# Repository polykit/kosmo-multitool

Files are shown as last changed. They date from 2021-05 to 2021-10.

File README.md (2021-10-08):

# Kosmo Multitool

This repository contains schematics, PCB and source code for a synthesizer module in Kosmo format. This module consists of an Arduino Nano Every, CV and gate input and output options, MIDI, rotary encoder and an OLED display. It is meant as a development platform for DIY synthesizer enthusiasts.

Here is a full list of features:
- 4x CV input (0-10V)
- 4x CV output (0-10V)
- 4x gate/trigger in
- 4x gate/trigger out
- 1.3" OLED display
- DIN serial MIDI in/through/out
- Rotary encoder with switch
- 3 switches
- 2 LEDs

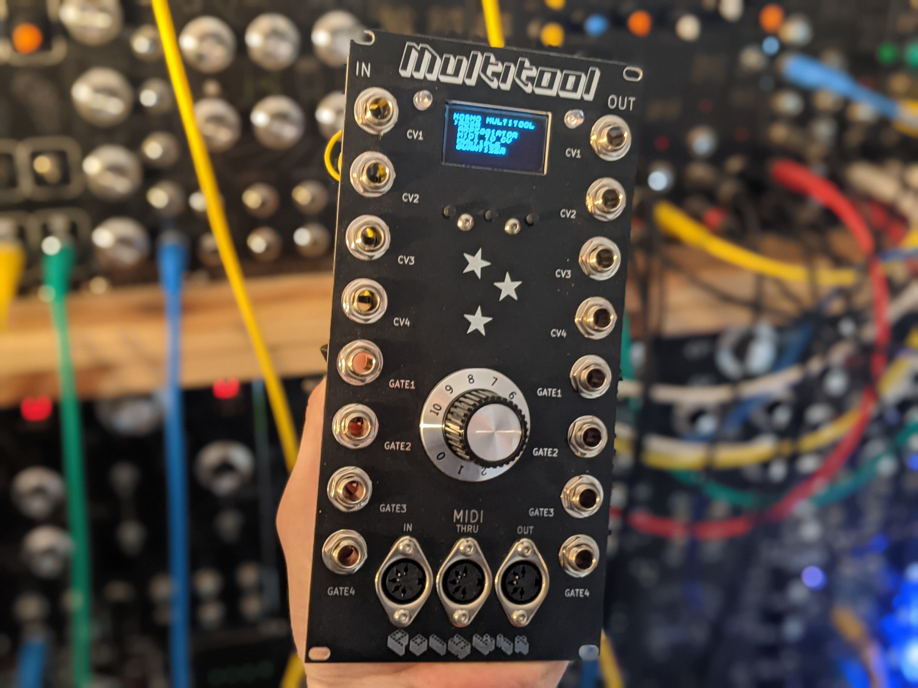
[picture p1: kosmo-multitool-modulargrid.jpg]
Kosmo Multitool Assembled


## Modules

- ADSR
- Arpeggiator
- MIDI to CV
- Multiple
- Quantizer

## Building

Gerbers for the main PCB can be found [here](plots) and for the front panel [here](panel/plots).

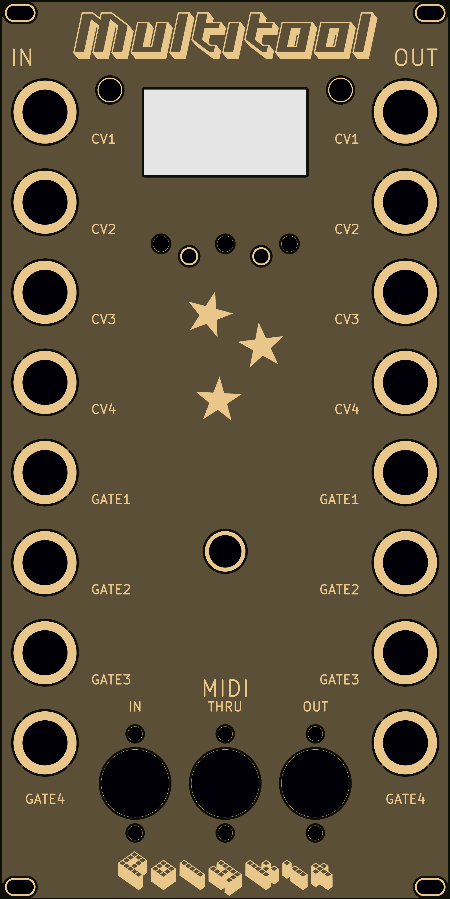
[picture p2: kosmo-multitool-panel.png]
Kosmo Multitool Panel
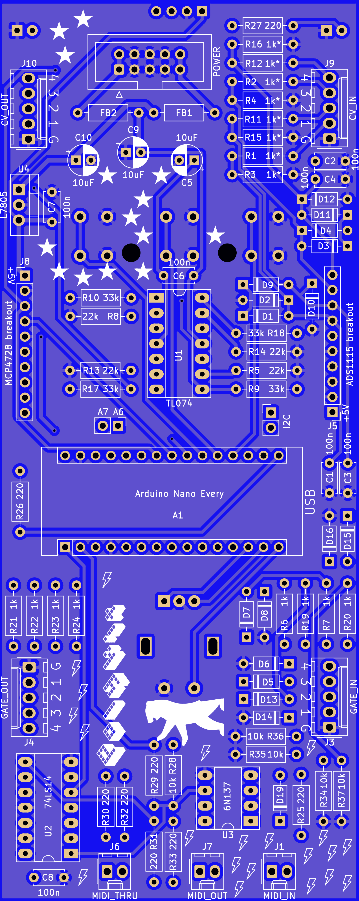
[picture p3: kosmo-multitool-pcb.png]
Kosmo Multitool PCB
 

### BOM

|Reference |Quantity|Value |Comment |
|---|---|---|---|
|A1 |1 |Arduino Nano Every | |
|C1 C2 C3 C4 C6 C7 C8 |7 |100n | |
|C5 C9 C10 |3 |10uF | |
|D17 D18 |2 |LED 5mm | |
|D1 D2 D3 D4 D5 D6 D7 D8 D9 D10 D11 D12 D13 D14 D15 D16 D19 |17 |1N4148 | |
|FB1 FB2 |2 |Ferrite Bead | |
|J1 |1 |MIDI_IN |Molex KK 2.54mm 2 pin |
|J10 |1 |CV_OUT |Molex KK 2.54mm 5 pin |
|J2 |1 |Display I2C |OLED display 1.3" 128x64 I2C SH1106 |
|J3 |1 |GATE_IN |Molex KK 2.54mm 5 pin |
|J4 |1 |GATE_OUT |Molex KK 2.54mm 5 pin |
|J5 |1 |ADS1115 breakout |ADC, pin order: VCC GND SCL SDA ADDR ALERT A B C D|
|J6 |1 |MIDI_THRU |Molex KK 2.54mm 2 pin |
|J7 |1 |MIDI_OUT |Molex KK 2.54mm 2 pin |
|J8 |1 |MCP4728 breakout |DAC, pin order: VCC GND SCL SDA LDAC READY A B C D|
|J9 |1 |CV_IN |Molex KK 2.54mm 5 pin |
|POWER1 |1 |POWER |IDC 10 pin |
|R1 R2 R3 R4 R11 R12 R15 R16 |8 |1k* | |
|R5 R8 R13 R14 |4 |22k | |
|R9 R10 R17 R18 |4 |33k | |
|R25 R26 R27 R29 R30 R31 R32 R33 |8 |220 | |
|R28 R34 R35 R36 R37 |5 |10k | |
|R6 R7 R19 R20 R21 R22 R23 R24 |8 |1k | |
|SW1 SW2 SW3 |3 |SW_Push |Tactile Push Button 6x6x15mm |
|SW4 |1 |Rotary_Encoder_Switch|Rotary encoder with switch, 20mm |
|U1 |1 |TL074 | |
|U2 |1 |74LS14 | |
|U3 |1 |6N137 | |
|U4 |1 |L7805 | |
| | |Pin sockets, 2.54mm  |Needed for the Arduino, OLED display, ADC and DAC |
| |16 |Jack sockets 6.35mm  | |
| |3 |DIN MIDI sockets | |

\* match in pairs to get more accurate ADC readings

## Installation and calibration

Clone the repository and open up the `src/main` folder in the Arduino IDE or whatever you use for compiling. You need to install the libraries mentioned below into you Arduino library folder. The ADC and the DAC need calibration to get proper results.

### ADC calibration
Set `CALIBRATE_CV_IN` variable in main file to `1`. Apply a fixed, known voltage to CV1 input, eg. 5.000V. On USB serial console (9600 baud) you get the actual reading from the ADC. Calculate the correction factor `FIXED VOLTAGE / ACTUAL VOLTAGE`, eg. `5.000 / 4.9884 = 1.0023`. Enter the value in the CV_IN_CORRECTION array in the top lines of `main.ino`. Repeat this procedure for all CV inputs. In the end it should look something like this:
```
float CV_IN_CORRECTION[4] = {0.9995f, 0.9956f, 1.0013f, 1.0009f};
```
Notice the trailing `f` to tell the compiler that these are float values. Don't forget to set `CALIBRATE_CV_IN` back to `0`.

### DAC calibration
Make sure to calibrate the ADC first. Set `CALIBRATE_CV_OUT` variable in main file to `1`. Plug in patch cables from all four CV inputs to the CV outputs. Calibration is done automatically and stored in a look-up table. Set `CALIBRATE_CV_OUT` back to `0`. This step is only needed once, from now on calibration values are loaded from EEPROM on start up.

## Development

Source code is in `src/main`. If you want to develop your own module just copy the files `example_module.h` and `example_module.ino` and rename all functions and variables that are globally available. Include your header file in the `main.ino` file and add your entry to the main menu. Take a look at the already existing modules on how it works in general. If you created a nice module please file a pull request and I would be happy to merge it.

## Libraries

https://github.com/adafruit/Adafruit_MCP4728

https://github.com/adafruit/Adafruit_ADS1X15

https://github.com/olikraus/u8g2

https://github.com/FortySevenEffects/arduino_midi_library

https://github.com/neu-rah/ArduinoMenu

https://github.com/thomasfredericks/Bounce2

https://github.com/mathertel/RotaryEncoder

https://github.com/ivanseidel/LinkedList

## References

https://www.lookmumnocomputer.com/modular

https://www.ti.com/lit/ds/symlink/ads1115.pdf

http://ww1.microchip.com/downloads/en/devicedoc/22187e.pdf

https://github.com/DylanMeeus/GoAudio

## License

This work is licensed under a [Creative Commons Attribution-NonCommercial 4.0 International License](http://creativecommons.org/licenses/by-nc/4.0/).

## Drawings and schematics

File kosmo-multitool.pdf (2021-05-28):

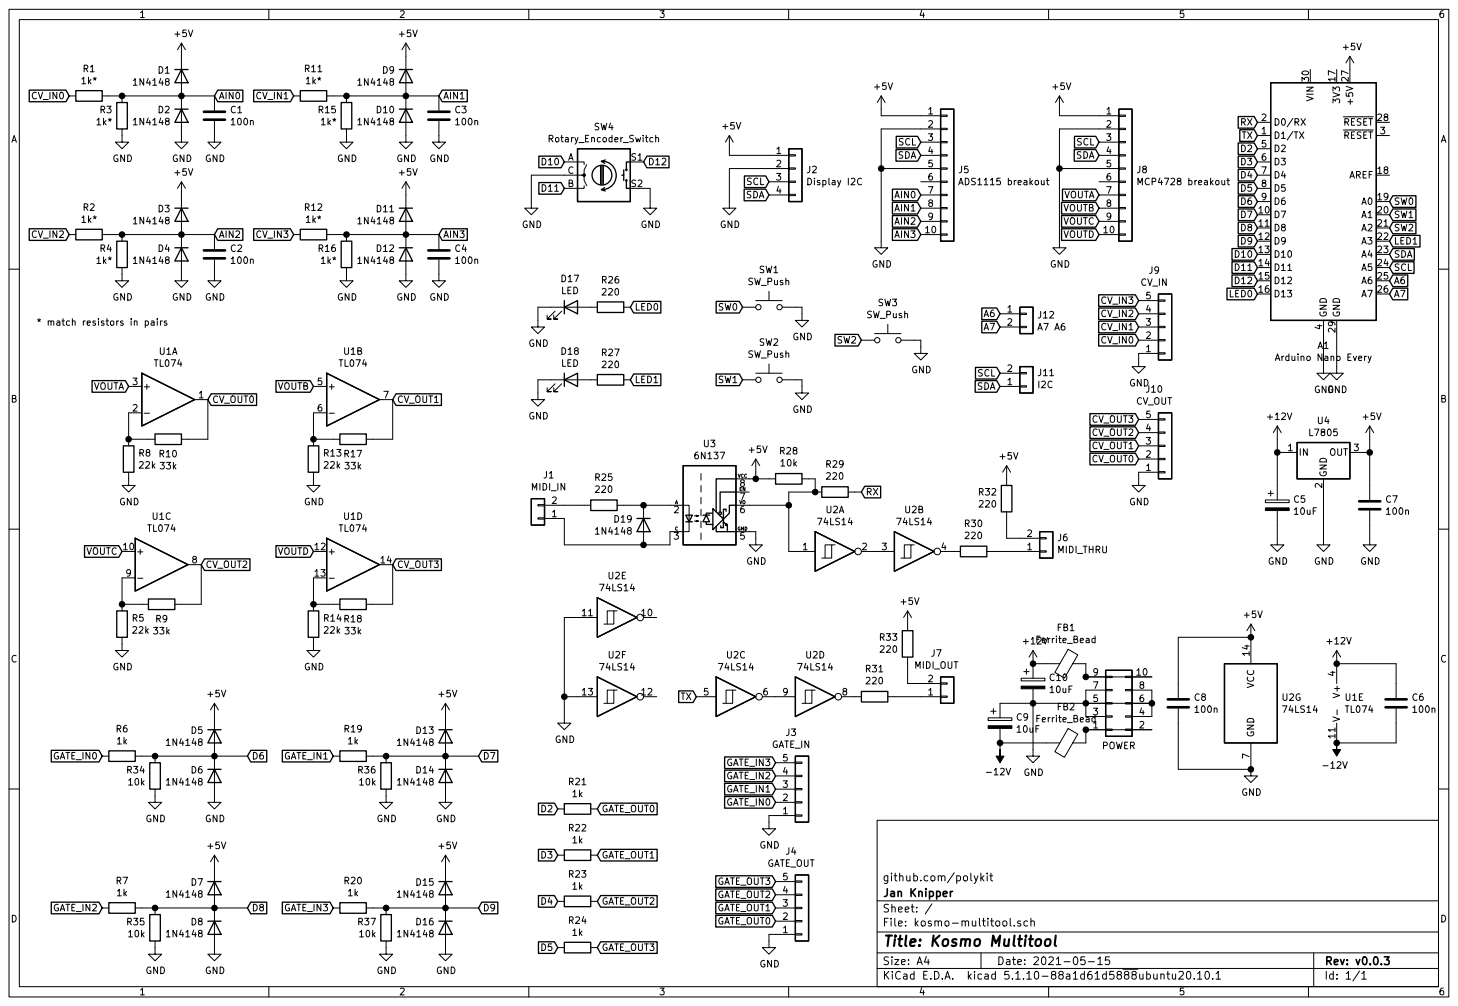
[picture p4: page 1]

* match resistors in pairs

Id: 1/1 Title: Kosmo Multitool File: kosmo-multitool.sch Sheet: / Jan Knipper

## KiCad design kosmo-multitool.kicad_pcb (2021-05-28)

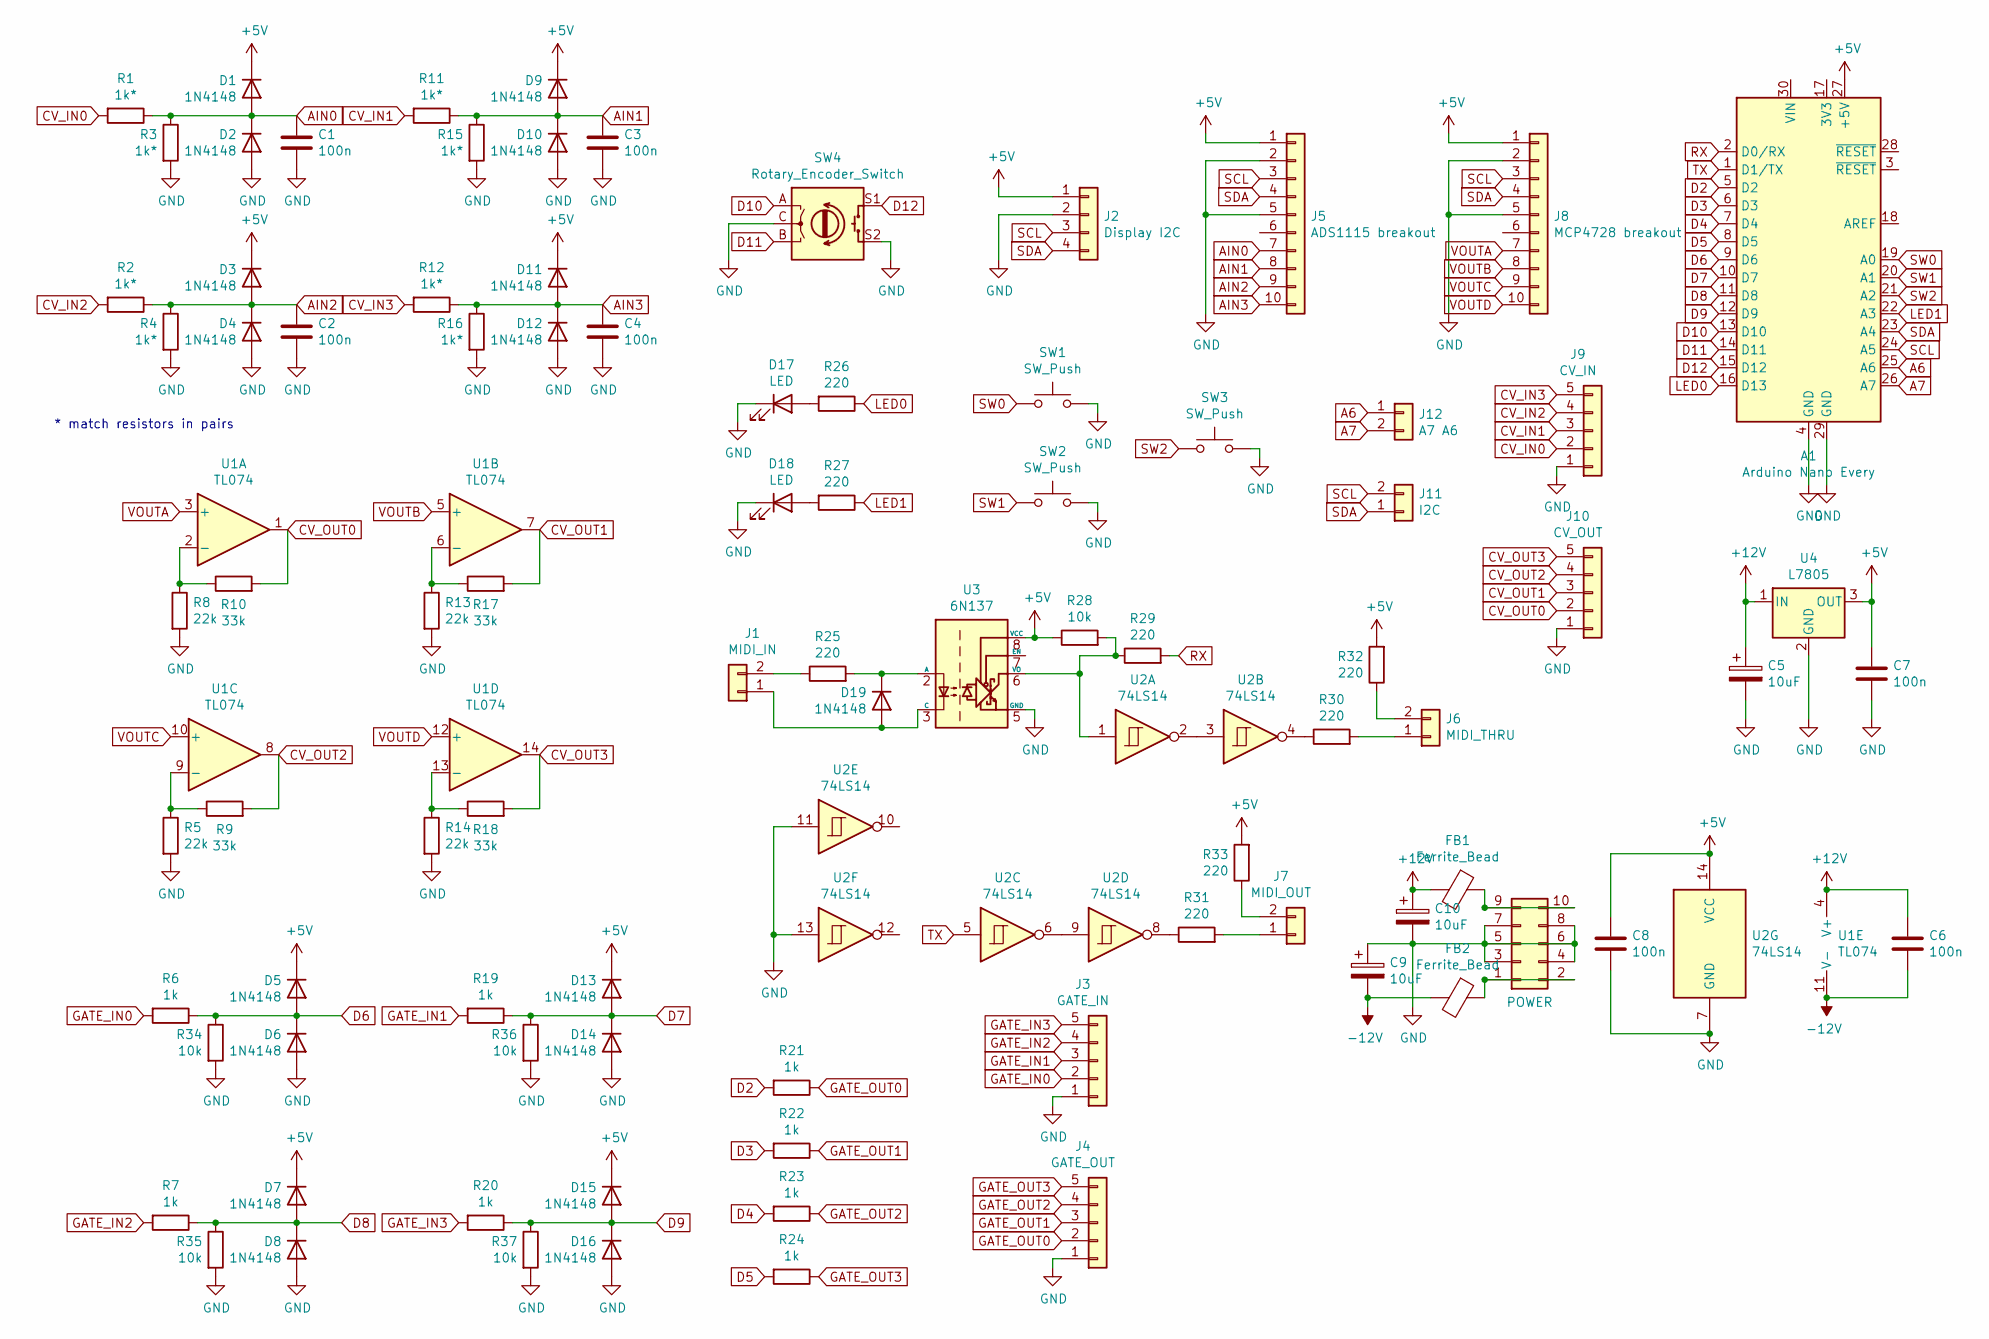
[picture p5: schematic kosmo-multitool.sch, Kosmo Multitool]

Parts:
A1: Arduino Nano Every; Arduino_Nano
C1, C2, C3, C4, C6, C7, C8: 100n; C_Disc_D5.0mm_W2.5mm_P5.00mm
C5, C9, C10: 10uF; CP_Radial_D5.0mm_P2.50mm
D1, D2, D3, D4, D5, D6, D7, D8, D9, D10, D11, D12, D13, D14, D15, D16, D19: 1N4148; D_DO-35_SOD27_P7.62mm_Horizontal
D17, D18: LED; LED_D5.0mm
FB1, FB2: Ferrite_Bead; R_Axial_DIN0207_L6.3mm_D2.5mm_P10.16mm_Horizontal
J1: MIDI_IN; Molex_KK-254_AE-6410-02A_1x02_P2.54mm_Vertical
J2: Display I2C; PinHeader_1x04_P2.54mm_Vertical
J3: GATE_IN; Molex_KK-254_AE-6410-05A_1x05_P2.54mm_Vertical
J4: GATE_OUT; Molex_KK-254_AE-6410-05A_1x05_P2.54mm_Vertical
J5: ADS1115 breakout; PinHeader_1x10_P2.54mm_Vertical
J6: MIDI_THRU; Molex_KK-254_AE-6410-02A_1x02_P2.54mm_Vertical
J7: MIDI_OUT; Molex_KK-254_AE-6410-02A_1x02_P2.54mm_Vertical
J8: MCP4728 breakout; PinHeader_1x10_P2.54mm_Vertical
J9: CV_IN; Molex_KK-254_AE-6410-05A_1x05_P2.54mm_Vertical
J10: CV_OUT; Molex_KK-254_AE-6410-05A_1x05_P2.54mm_Vertical
J11: I2C; PinHeader_1x02_P2.54mm_Vertical
J12: A7 A6; PinHeader_1x02_P2.54mm_Vertical
POWER1: POWER; IDC-Header_2x05_P2.54mm_Vertical
R1, R2, R3, R4, R11, R12, R15, R16: 1k*; R_Axial_DIN0207_L6.3mm_D2.5mm_P10.16mm_Horizontal
R5, R8, R13, R14: 22k; R_Axial_DIN0207_L6.3mm_D2.5mm_P10.16mm_Horizontal
R6, R7, R19, R20, R21, R22, R23, R24: 1k; R_Axial_DIN0207_L6.3mm_D2.5mm_P10.16mm_Horizontal
R9, R10, R17, R18: 33k; R_Axial_DIN0207_L6.3mm_D2.5mm_P10.16mm_Horizontal
R25, R26, R27, R29, R30, R31, R32, R33: 220; R_Axial_DIN0207_L6.3mm_D2.5mm_P10.16mm_Horizontal
R28, R34, R35, R36, R37: 10k; R_Axial_DIN0207_L6.3mm_D2.5mm_P10.16mm_Horizontal
SW1, SW2, SW3: SW_Push; SW_PUSH_6mm_H13mm
SW4: Rotary_Encoder_Switch; RotaryEncoder_Alps_EC11E-Switch_Vertical_H20mm
U1: TL074; DIP-14_W7.62mm_Socket_LongPads
U2: 74LS14; DIP-14_W7.62mm_Socket_LongPads
U3: 6N137; DIP-8_W7.62mm_Socket_LongPads
U4: L7805; TO-220-3_Vertical

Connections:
+5V: A1.27 (+5V), C7.1, C8.1, D1.1 (K), D3.1 (K), D5.1 (K), D7.1 (K), D9.1 (K), D11.1 (K), D13.1 (K), D15.1 (K), J2.1, J5.1, J8.1, R28.1, R32.2, R33.2, U2.14 (VCC), U3.8 (VCC), U4.3 (OUT)
+12V: C5.1, C6.1, C10.1, FB1.2, U1.4 (V+), U4.1 (IN)
-12V: C6.2, C9.2, FB2.2, U1.11 (V-)
A6: A1.25 (A6), J12.1
A7: A1.26 (A7), J12.2
AIN0: C1.1, D1.2 (A), D2.1 (K), J5.7, R1.1, R3.1
AIN1: C3.1, D9.2 (A), D10.1 (K), J5.8, R11.1, R15.1
AIN2: C2.1, D3.2 (A), D4.1 (K), J5.9, R2.1, R4.1
AIN3: C4.1, D11.2 (A), D12.1 (K), J5.10, R12.1, R16.1
CV_IN0: J9.2, R1.2
CV_IN1: J9.3, R11.2
CV_IN2: J9.4, R2.2
CV_IN3: J9.5, R12.2
CV_OUT0: J10.2, R10.2, U1.1
CV_OUT1: J10.3, R17.2, U1.7
CV_OUT2: J10.4, R9.2, U1.8
CV_OUT3: J10.5, R18.2, U1.14
D2: A1.5 (D2), R21.2
D3: A1.6 (D3), R22.2
D4: A1.7 (D4), R23.2
D5: A1.8 (D5), R24.2
D6: A1.9 (D6), D5.2 (A), D6.1 (K), R6.1, R34.1
D7: A1.10 (D7), D13.2 (A), D14.1 (K), R19.1, R36.1
D8: A1.11 (D8), D7.2 (A), D8.1 (K), R7.1, R35.1
D9: A1.12 (D9), D15.2 (A), D16.1 (K), R20.1, R37.1
D10: A1.13 (D10), SW4.A
D11: A1.14 (D11), SW4.B
D12: A1.15 (D12), SW4.S1
GATE_IN0: J3.2, R6.2
GATE_IN1: J3.3, R19.2
GATE_IN2: J3.4, R7.2
GATE_IN3: J3.5, R20.2
GATE_OUT0: J4.2, R21.1
GATE_OUT1: J4.3, R22.1
GATE_OUT2: J4.4, R23.1
GATE_OUT3: J4.5, R24.1
GND: A1.4 (GND), A1.29 (GND), C1.2, C2.2, C3.2, C4.2, C5.2, C7.2, C8.2, C9.1, C10.2, D2.2 (A), D4.2 (A), D6.2 (A), D8.2 (A), D10.2 (A), D12.2 (A), D14.2 (A), D16.2 (A), D17.1 (K), D18.1 (K), J2.2, J3.1, J4.1, J5.2, J5.5, J8.2, J8.5, J9.1, J10.1, POWER1.3, POWER1.4, POWER1.5, POWER1.6, POWER1.7, POWER1.8, R3.2, R4.2, R5.2, R8.2, R13.2, R14.2, R15.2, R16.2, R34.2, R35.2, R36.2, R37.2, SW1.2, SW2.2, SW3.2, SW4.C, SW4.S2, U2.7 (GND), U2.11, U2.13, U3.5 (GND), U4.2 (GND)
LED0: A1.16 (D13), R26.1
LED1: A1.22 (A3), R27.1
unnamed: D17.2 (A), R26.2
unnamed: D18.2 (A), R27.2
unnamed: D19.1 (K), R25.2, U3.2 (A)
unnamed: D19.2 (A), J1.1, U3.3 (C)
unnamed: FB1.1, POWER1.9, POWER1.10
unnamed: FB2.1, POWER1.1, POWER1.2
unnamed: J1.2, R25.1
unnamed: J6.1, R30.2
unnamed: J6.2, R32.1
unnamed: J7.1, R31.2
unnamed: J7.2, R33.1
unnamed: R5.1, R9.1, U1.9 (-)
unnamed: R8.1, R10.1, U1.2 (-)
unnamed: R13.1, R17.1, U1.6 (-)
unnamed: R14.1, R18.1, U1.13 (-)
unnamed: R28.2, R29.1, U2.1, U3.6 (VO)
unnamed: R30.1, U2.4
unnamed: R31.1, U2.8
unnamed: U2.2, U2.3
unnamed: U2.6, U2.9
RX: A1.2 (D0/RX), R29.2
SCL: A1.24 (A5), J2.3, J5.3, J8.3, J11.2
SDA: A1.23 (A4), J2.4, J5.4, J8.4, J11.1
SW0: A1.19 (A0), SW1.1
SW1: A1.20 (A1), SW2.1
SW2: A1.21 (A2), SW3.1
TX: A1.1 (D1/TX), U2.5
VOUTA: J8.7, U1.3 (+)
VOUTB: J8.8, U1.5 (+)
VOUTC: J8.9, U1.10 (+)
VOUTD: J8.10, U1.12 (+)

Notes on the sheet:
* match resistors in pairs

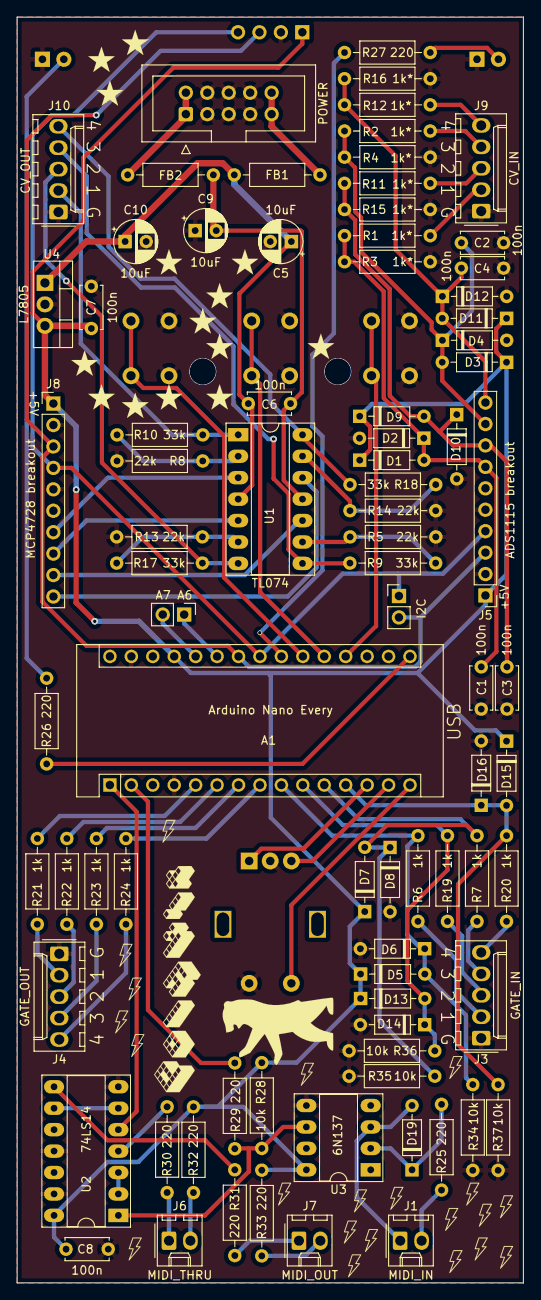
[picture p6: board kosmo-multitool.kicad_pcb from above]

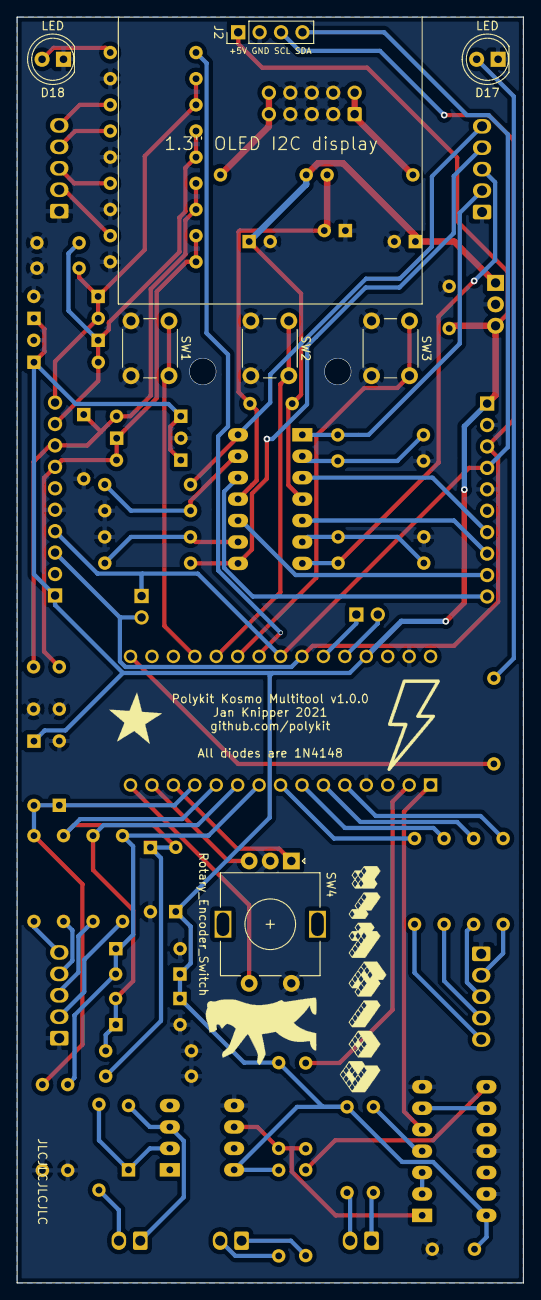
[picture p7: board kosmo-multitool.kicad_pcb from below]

Board: 2 copper layers, 60.0 x 150.0 mm, 90 parts (7 on the bottom side), 70 nets.

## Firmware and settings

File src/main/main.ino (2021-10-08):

#include <Arduino.h>
#include <EEPROM.h>
#include <Wire.h>

#include <Adafruit_ADS1X15.h>
#include <Adafruit_MCP4728.h>
#include <MIDI.h>
#include <menu.h>
#include <menuIO/U8x8Out.h>
#include <U8x8lib.h>
#include <RotaryEncoder.h>
#include <Bounce2.h>
#include <LinkedList.h>

//#include "example_module.h"
#include "adsr.h"
#include "arp.h"
#include "midi2cv.h"
#include "multiple.h"
#include "quantizer.h"

#define DEBUG 1
#define CALIBRATE_CV_IN 0
#define CALIBRATE_CV_OUT 0

float CV_IN_CORRECTION[4] = {1.0000f, 1.0000f, 1.0000f, 1.0000f};
unsigned int CV_OUT_LUT[4][21];
int LED_PINS[2] = {13, A3};
int GATE_IN_PINS[4] = {6, 7, 8, 9};
int GATE_OUT_PINS[4] = {2, 3, 4, 5};
unsigned long GATE_OUT_DURATION[4];
int SWITCH_PINS[4] = {A0, A1, A2, 12};
Bounce2::Button SWITCHES[4];
int MIDI_CHANNEL = 1;
int OCTAVE_OFFSET = 3;
LinkedList<byte> MIDI_NOTES_ACTIVE;
void (*activeModule)(void);

Adafruit_ADS1115 ads;
Adafruit_MCP4728 mcp;
U8X8_SH1106_128X64_NONAME_HW_I2C u8x8(U8X8_PIN_NONE);
MIDI_CREATE_INSTANCE(HardwareSerial, Serial1, MIDI);
RotaryEncoder encoder(10, 11, RotaryEncoder::LatchMode::TWO03);

// menu
MENU(mainMenu,"KOSMO MULTITOOL",doNothing,noEvent,wrapStyle
  //,SUBMENU(subMenuExample)
  ,SUBMENU(subMenuADSR)
  ,SUBMENU(subMenuArp)
  ,SUBMENU(subMenuMidi2CV)
  ,SUBMENU(subMenuMultiple)
  ,SUBMENU(subMenuQuantizer)
);
#define MAX_DEPTH 3
noInput in;
MENU_OUTPUTS(out,MAX_DEPTH,U8X8_OUT(u8x8,{0,0,17,8}),NONE);
NAVROOT(nav,mainMenu,MAX_DEPTH,in,out);

void setup(void) {
  if (DEBUG) {
    Serial.begin(9600);
    Serial.println("Polykit Multitool. Initializing...");
  }
  
  // initialize adc
  ads.setGain(GAIN_TWOTHIRDS);
  ads.begin();

  // initialize dac
  mcp.begin();

  // init midi
  MIDI.setHandleNoteOn(handleNoteOn);
  MIDI.setHandleNoteOff(handleNoteOff);
  MIDI.begin(MIDI_CHANNEL);

  // init display
  u8x8.begin();
  u8x8.setFont(u8x8_font_chroma48medium8_u);
  
  for (int i=0; i<2; i++) {
    pinMode(LED_PINS[i], OUTPUT);
  }

  for (int i=0; i<4; i++) {
    pinMode(GATE_IN_PINS[i], INPUT);
    pinMode(GATE_OUT_PINS[i], OUTPUT);
    GATE_OUT_DURATION[i] = 0;
  }

  for (int i=0; i<4; i++) {
    SWITCHES[i] = Bounce2::Button();
    SWITCHES[i].attach(SWITCH_PINS[i], INPUT_PULLUP);
    SWITCHES[i].interval(10); 
    SWITCHES[i].setPressedState(LOW); 
  } 

  if (CALIBRATE_CV_IN) {
    u8x8.drawString(0,0,"CALIBRATING...");
    calibrateCVIn();
    u8x8.drawString(0,1,"DONE");
    while (1);
  } 

  if (CALIBRATE_CV_OUT) {
    u8x8.drawString(0,0,"CALIBRATING...");
    calibrateCVOut();
    u8x8.drawString(0,1,"DONE");
    while (1);
  } else {
    u8x8.drawString(0,0,"LOADING...");
    int addr = 0;
    for (int c=0; c<4; c++) {
      CV_OUT_LUT[c][0] = 0;
      for (int i=1; i<=20; i++) {
        EEPROM.get(addr, CV_OUT_LUT[c][i]);
        addr += sizeof(unsigned int);
      }
    }
  }

  for (int i=0; i<4; i++) {
    setLEDOn(0);
    setLEDOff(1);
    delay(100);
    setLEDOn(1);
    setLEDOff(0);
    delay(100);
  }
  setLEDOff(1);
}

void loop(void) {
  MIDI.read();
  encoder.tick();
  nav.poll();
  handleMenu();
  handleGateOutDurations();
  handleSwitches();
  if (activeModule) {
    activeModule();
  }
}

void handleNoteOn(byte channel, byte note, byte velocity) {
  if (channel != MIDI_CHANNEL) return;
  MIDI_NOTES_ACTIVE.add(note);
}

void handleNoteOff(byte channel, byte note, byte velocity) {
  if (channel != MIDI_CHANNEL) return;
  for (int i=0; i<MIDI_NOTES_ACTIVE.size(); i++) {
    if (MIDI_NOTES_ACTIVE.get(i) == note) {
      MIDI_NOTES_ACTIVE.remove(i);
      return;
    }
  }
}

float getCVFromNote(byte note) {
  return (note-12*OCTAVE_OFFSET)/12.0f;
}

void handleMenu() {
  int dir = getEncoderDir();
  if (dir == (int)RotaryEncoder::Direction::COUNTERCLOCKWISE) {
    nav.doNav(navCmd(downCmd));
  } else if(dir == (int)RotaryEncoder::Direction::CLOCKWISE) {
    nav.doNav(navCmd(upCmd));    
  }
  if (isSwitchOn(3)) {
    nav.doNav(navCmd(enterCmd));
  }
}

int getEncoderDir() {
  return (int)encoder.getDirection();
}

int getEncoderPos() {
  return encoder.getPosition();
}

float getCVIn(int n, bool correct) {
  if (n>3) return -1;
  
  int16_t adc = ads.readADC_SingleEnded(n);
  float cv = ads.computeVolts(adc)*2;
  
  if (correct) {
    cv = cv*CV_IN_CORRECTION[n];
  }
  
  return cv;
}

void setCVOut(int n, float v, bool correct) {
  if (n>3) return;
  if (v>10) return;
  
  MCP4728_channel_t ch;
  if (n==0) ch = MCP4728_CHANNEL_A;
  if (n==1) ch = MCP4728_CHANNEL_B;
  if (n==2) ch = MCP4728_CHANNEL_C;
  if (n==3) ch = MCP4728_CHANNEL_D;
  int nv = map(v*1000, 0, 10000, 0, 4095);

  if (correct) {
    int pos = round(2*v);
    nv = nv*(CV_OUT_LUT[n][pos]/1000.0f);
  }

  mcp.setChannelValue(ch, nv, MCP4728_VREF_INTERNAL, MCP4728_GAIN_2X);
}

void calibrateCVIn() {
  if (DEBUG) Serial.println("ADC calibration started.");
  int numSamples = 20;
  for (int n=0; n<4; n++) {
    if (DEBUG) {
      Serial.print("CV");
      Serial.print(n);
      Serial.print("CV");
    }
    float cv = 0;
    for (int i=0; i<numSamples; i++) {
      cv += getCVIn(n, false);
    }
    if (DEBUG) Serial.println((cv/numSamples), 4);
  }
  if (DEBUG) Serial.println("ADC calibration ended.");
}

void calibrateCVOut() {
  if (DEBUG) Serial.println("DAC calibration started.");
  int numSamples = 20;
  float cv;
  int addr = 0;
  for (int c=0; c<4; c++) {
    if (DEBUG) {
      Serial.print("Channel: ");
      Serial.println(c);
    }
    CV_OUT_LUT[c][0] = 0;
    for (int i=1; i<=20; i++) {
      setCVOut(c, i*0.5f, false);
      delay(100);
      cv = 0;
      for (int j=0; j<numSamples; j++) {
        cv += getCVIn(c, true);
      }
      cv = cv/numSamples;
      CV_OUT_LUT[c][i] = round(1000*i*0.5f/cv);
      if (DEBUG) {
        Serial.print("Wanted: ");
        Serial.println(i*0.5f, 4);
        Serial.print("Real: ");
        Serial.println(cv, 4);
        Serial.print("LUT: ");
        Serial.println(CV_OUT_LUT[c][i]/1000.0f, 4);
      }
      EEPROM.put(addr, CV_OUT_LUT[c][i]);
      addr += sizeof(unsigned int);
    }
  }
  if (DEBUG) Serial.println("DAC calibration ended.");
}

void setGateOutDuration(int n, unsigned long duration_ms) {
  if (n>3) return;
  GATE_OUT_DURATION[n] = millis()+duration_ms;
  setGateOutHigh(n);
}

void handleGateOutDurations() {
  for (int n=0; n<4; n++) {
    if (GATE_OUT_DURATION[n] > 0) {
      long d = GATE_OUT_DURATION[n]-millis();
      if (d < 0) {
        setGateOutLow(n);
        GATE_OUT_DURATION[n] = 0;
      }
    }
  }
}

void setGateOutHigh(int n) {
  if (n>3) return;
  digitalWrite(GATE_OUT_PINS[n], HIGH);
}

void setGateOutLow(int n) {
  if (n>3) return;
  digitalWrite(GATE_OUT_PINS[n], LOW);
}

void setGateOut(int n, bool b) {
  if (n>3) return;
  digitalWrite(GATE_OUT_PINS[n], b);
}

bool getGateIn(int n) {
  if (n>3) return -1;
  return (bool)digitalRead(GATE_IN_PINS[n]);
}

void handleSwitches() {
  for (int n=0; n<4; n++) {
    SWITCHES[n].update();
  }
}

bool isSwitchOn(int n) {
  if (n>3) return 0;
  bool pressed = SWITCHES[n].pressed();
  return pressed;
}

void setLEDOn(int n) {
  if (n>1) return;
  digitalWrite(LED_PINS[n], HIGH);
}

void setLEDOff(int n) {
  if (n>1) return;
  digitalWrite(LED_PINS[n], LOW);
}

void resetCVOut() {
  for(int i=0; i<4; i++) {
    setCVOut(i, 0, false);
  }
}

void resetGateOut() {
  for(int i=0; i<4; i++) {
    setGateOutLow(i);
  }
}

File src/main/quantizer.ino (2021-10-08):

result handleQuantizer(eventMask event, navNode& nav, prompt &item) {
  if (event == enterEvent) {
    startQuantizer();
    activeModule = &loopQuantizer;
  }
  if (event == exitEvent) {
    activeModule = {};
    endQuantizer();
  }
  return proceed;
}

// called once on module enter
void startQuantizer() {
}

// called once on module exit
void endQuantizer() {
  resetCVOut();
  resetGateOut();
}

float quantLastCV = 0;

// called constantly from main loop
void loopQuantizer() {
  float cv = quantLastCV;

  if (!quantTrigger || getGateIn(0)) {
    cv = getCVIn(0, true);
    cv = round(12 * cv) * (1 / 12.0f) +  quantOffset;
    if (cv < 0 ) cv = 0;
  }

  if (cv != quantLastCV) {
    setCVOut(0, cv, true);
    setGateOutDuration(0, 10);
    quantLastCV = cv;
  }
}
